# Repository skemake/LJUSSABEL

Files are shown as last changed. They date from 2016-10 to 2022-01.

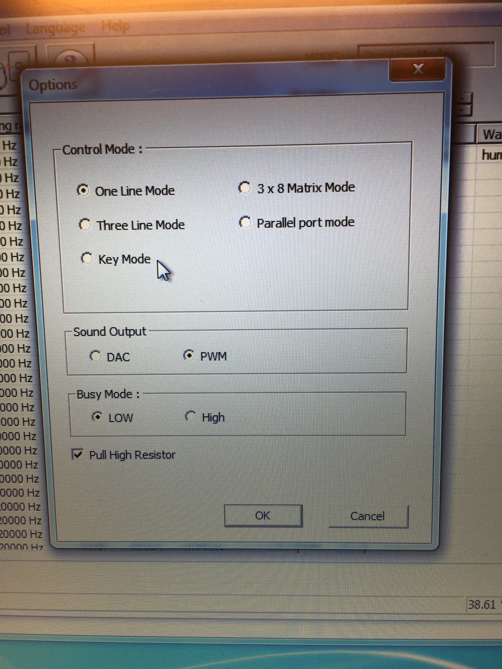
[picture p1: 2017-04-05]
Hardware/flags_wt588d_programmer.jpg

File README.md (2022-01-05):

#LJUSSABEL

##Introduction
LJUSSABEL is a low-cost, make-it-yourself lightsaber. Made with an aluminium shaft, tough polycarbonate blade and runs on an Arduino Pro Mini.

##Background
LJUSSABEL is the result of a question posed to one of SkeMakes founding members. A local martial arts club was invited to arrange a Star-Wars themed live roleplay event for kids at the annual game/movie/comic convention Nordsken. They had sourced some clear polycarbonate tubes from a company making snow season road markers and wanted to know if it was possible to find a cheap way to light them up to emulate lightsabers. After some intensive googling, our reply was: "Yes, and we can add sound to them too!". 

##What
The sabers feature light, sound and motion/clash sensitivity. They are tough enough to fight with (tested by the local Kendoka) and suitable for both kids and adults.

##Who
LJUSSABEL is developed by community and in collaboration with other non-profit organisations. The circuitry and design is made by one of our members and the soldering, programming and general problem solving has been done by the members on a volunteer basis.

It's a co-creative, open source, collaborative project made by creative makers and devoted people working together.

##Assembly instructions
Instructions (so far only in Swedish) for assembling a lightsaber are available in this document: https://docs.google.com/document/d/1xrwHwMRmk5lazxgZUJuRNKeTjP84kaqsUcIwcMbUZiY.

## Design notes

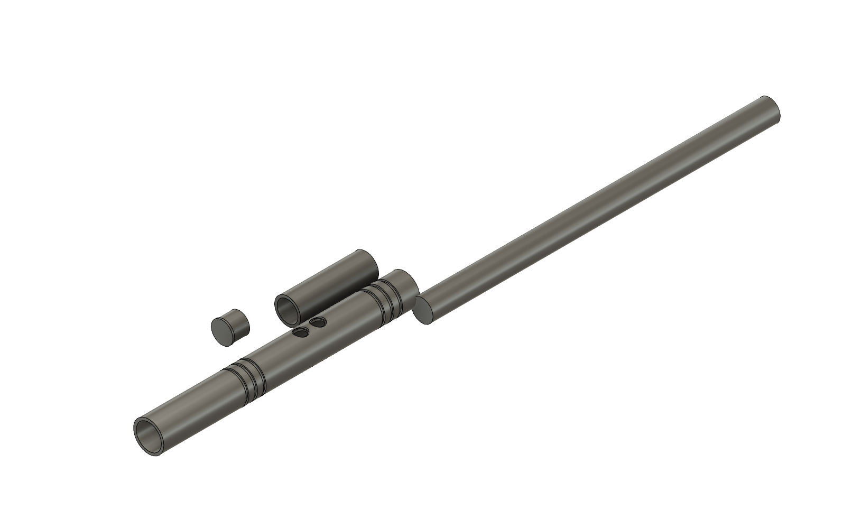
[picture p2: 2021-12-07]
Hardware/Drawings/LJUSSABEL.png

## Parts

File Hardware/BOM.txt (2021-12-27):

Bill of Materials

- Circuit board: After brd file in this repository

On top of this moderboard the following components are mounted:
- Moderboard: Arduino Pro Mini 328 - 5V/16MHz
- DC-DC converter: 5V to 3.3V
- Sound chip: WT588D
- Accelerometer: GY-61
- Power MOSFET: 3 pcs 14n05
- Diode: 2 pcs 1n4148
- Resistor: 1pcs 568ohm
- Vibration sensor: SW18010P

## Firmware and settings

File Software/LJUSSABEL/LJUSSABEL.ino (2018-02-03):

#include "OneButton.h"
#include "RGBLED.h"
#include "OneLineWT588D.h"
#include "Motion.h"
#include "SoundFont.h"
#include "SM.h"
#include "ColorGem.h"

// Uncomment next line to enable debug traces
//#define DEBUG
#include "Debug.h"

// Button
#define SW_ACT_PIN 8

// LED PWM pins
#define LED_RED_PIN 9
#define LED_GREEN_PIN 6
#define LED_BLUE_PIN 5

// Unused PWM pins for extra LED
//#define LED_ACCENT_RED_PIN 10
//#define LED_ACCENT_GREEN_PIN 3
//#define LED_ACCENT_BLUE_PIN 12

// Sound chip
#define WT588D_DATA_PIN 4
#define WT588D_BUSY_PIN 7
#define WT588D_RESET_PIN 11

// Accelerometer
#define GY_61_GND_PIN 13
#define GY_61_VCC_PIN A4
#define GY_61_X_PIN A2
#define GY_61_Y_PIN A1
#define GY_61_Z_PIN A0

// Clash switch
#define CLASH_PIN 2

// Crystal pins (voltage divider circuit)
#define COLOR_GEM_ANALOG_PIN A3
#define COLOR_GEM_DIGITAL_PIN 12

// Used to get random seed for sound selection
#define RANDOMSEED_PIN A5

// Global for clash sensor debounce
uint32_t clash_interrupt_time;
// Clash interrupt flag
bool clashInterruptTriggered=false;
// Do not trigger swings directly after clash
#define CLASH_SWING_OVERRIDE_DURATION 1000


// Minimum swing sound time
#define SWING_SOUND_DURATION 1000
uint32_t swing_interrupt_time;

// Init
OneButton ButtonAct(SW_ACT_PIN, true);
RGBLED Led(LED_RED_PIN,LED_GREEN_PIN,LED_BLUE_PIN);
OneLineWT588D Soundchip(WT588D_DATA_PIN,WT588D_BUSY_PIN,WT588D_RESET_PIN);
Motion Accelerometer(GY_61_X_PIN, GY_61_Y_PIN, GY_61_Z_PIN, 3.3, GY_61_VCC_PIN, GY_61_GND_PIN);
ColorGem BladeGem(COLOR_GEM_ANALOG_PIN, COLOR_GEM_DIGITAL_PIN);

//Set state machine to initial state.
State waitStateRunOnce(); // preallocate
State waitState(); // preallocate
SM Machine(waitStateRunOnce, waitState); // create state machine
void enterWaitState(){ Machine.Set(waitStateRunOnce, waitState); }
void enterLitState(){ Machine.Set(litStateRunOnce, litState); }
void enterLockupState(){ Machine.Set(lockupStateRunOnce, lockupState); }

void setup()
{
  trace_begin(115200);
  trace("Blade initializing...");

  Soundchip.warmUp();

  ButtonAct.setClickTicks(150); //600 default (debounce 60)
  ButtonAct.setPressTicks(500); // 1000 default

  // clash sensor
  digitalWrite (CLASH_PIN, HIGH);
  attachInterrupt(digitalPinToInterrupt(CLASH_PIN), clashInterrupt, FALLING);
  clash_interrupt_time = millis();

  swing_interrupt_time = millis();

  delay(200);

  // Init blade color
  trace(BladeGem.getValue());
  BladeGem.readGem();
  Led.setValue(BladeGem.getRed(),BladeGem.getGreen(),BladeGem.getBlue());

  //set seed for the random() in SoundFont.h
  randomSeed(analogRead(RANDOMSEED_PIN));
  enterWaitState();
}

void loop()
{
  // Update everything
  Accelerometer.update();
  ButtonAct.tick();
  Led.poke();
  EXEC(Machine);
}

State waitStateRunOnce()
{
  trace("Enter wait state.");
  // set button function pointers
  ButtonAct.attachClick(enterLitState);
  ButtonAct.attachLongPressStart(enterLitState);

  // disable other functions
  ButtonAct.attachDoubleClick(buttonDisabled);
  ButtonAct.attachDuringLongPress(buttonDisabled);
  ButtonAct.attachLongPressStop(buttonDisabled);

  // led off
  if(Led.fadeOut(500)) // returns true if led was on
  {
    Soundchip.play(getRandom(fx_poweroff));
  }
  else
  {
    Soundchip.play(getRandom(fx_boot));
    Led.turnOff();
  }
}

State waitState()
{
}

State litStateRunOnce()
{
  trace("Enter lit state.");

  // set button function pointers
  ButtonAct.attachClick(enterWaitState); // turn led off
  ButtonAct.attachLongPressStart(enterLockupState);

  // disable all else
  ButtonAct.attachDoubleClick(buttonDisabled);
  ButtonAct.attachDuringLongPress(buttonDisabled);
  ButtonAct.attachLongPressStop(buttonDisabled);

  // Clear any clash interrupts that happened in lockup state
  clashInterruptTriggered = false;

  Led.setFlicker(0);

  if(Led.fadeIn(500)) // returns true if led was off
  {
    Soundchip.play(getRandom(fx_poweron));
  }
  else
  { // led is on, so we should be humming already (e.g. returning from lockup)
    Soundchip.play(getRandom(fx_hum));
    Soundchip.repeat();
  }
}

State litState()
{
  if(Accelerometer.isSwinging())
  {
    swing();
  }

  if(clashInterruptTriggered)
  {
    clash();
  }

  // Restart humming if we have silence
  if(Soundchip.isBusy() == false)
  {
    trace("Restart humming");
    Soundchip.play(getRandom(fx_hum));
    Soundchip.repeat();
  }
}

State lockupStateRunOnce()
{
  trace("Enter lockup state.");

  // set button function pointers
  ButtonAct.attachClick(enterWaitState); // turn led off
  ButtonAct.attachLongPressStop(enterLitState);

  // disable all else
  ButtonAct.attachDoubleClick(buttonDisabled);
  ButtonAct.attachLongPressStart(buttonDisabled);
  ButtonAct.attachDuringLongPress(buttonDisabled);

  Soundchip.play(getRandom(fx_lockup));
  Soundchip.repeat();
}

State lockupState()
{
  Led.setFlicker(5);
}

/*
void deflect(){
  Led.flash(255,255,255);
  Soundchip.play(getRandom(fx_blaster));
}*/

void swing()
{
  if ((millis() - clash_interrupt_time) < CLASH_SWING_OVERRIDE_DURATION)
  {
    // Do not allow swings directly after clash, since the blade bounce oftern trigger flase swings
    trace("swing clash override");
  }
  else
  {
    if (millis() - swing_interrupt_time > SWING_SOUND_DURATION)
    {
      trace("Swing.");
      Accelerometer.swingTrace();
      Soundchip.play(getRandom(fx_swing));
      swing_interrupt_time = millis();
    }
  }
}

void clash()
{
  trace("Clash.");
  Led.flash(255,255,255);
  Soundchip.play(getRandom(fx_clash));
  clashInterruptTriggered = false;
}

void clashInterrupt()
{
  if(Led.getState()==on)
  {
    if (millis() - clash_interrupt_time > 200)
    {
      clashInterruptTriggered = true;
      trace("interrupt");
      clash_interrupt_time = millis();
    }
  }
}

void buttonDisabled()
{
  // do nothing
}

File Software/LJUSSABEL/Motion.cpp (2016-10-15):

#include "Motion.h"

//#define DEBUG
#include "Debug.h"


Motion::Motion(uint8_t pin_x, uint8_t pin_y, uint8_t pin_z, float aref, uint8_t pin_vcc, uint8_t pin_gnd){
	pinMode(pin_gnd, OUTPUT);
	digitalWrite(pin_gnd, LOW);
	pinMode(pin_vcc, OUTPUT);
	digitalWrite(pin_vcc, HIGH);
	
	_aref = aref;
	_pin_x = pin_x;
	_pin_y = pin_y;
	_pin_z = pin_z;
	_mvG = aref / 10.0;
	_bias = aref / 2.0;
	_rad2deg = 180.0 / M_PI;
  _swing_start_time = millis();
  _deltaX=0;
  _deltaY=0;
  _deltaZ=0;
}
void Motion::update(){
	_xg = getGravity(analogRead(_pin_x));
	_yg = getGravity(analogRead(_pin_y));
	_zg = getGravity(analogRead(_pin_z));

  if (millis() - _swing_start_time > SWING_SAMPLE_TIME)
  {
    _deltaX = _maxX - _minX;
    _deltaY = _maxY - _minY;
    _deltaZ = _maxZ - _minZ;
    
    _minX=_xg;
    _maxX=_xg;
    _minY=_yg;
    _maxY=_yg;
    _minZ=_zg;
    _maxZ=_zg;
    
    _swing_start_time = millis();
  }
  if(_xg < _minX) _minX = _xg;
  if(_xg > _maxX) _maxX = _xg;
  if(_yg < _minY) _minY = _yg;
  if(_yg > _maxY) _maxY = _yg;
  if(_zg < _minZ) _minZ = _zg;
  if(_zg > _maxZ) _maxZ = _zg;

}

float Motion::getDeltaSum()
{
  return (_deltaX + _deltaY + _deltaZ);
}

float Motion::getGravity(uint16_t reading)
{
  float voltage = reading * _aref;
  voltage /= 1024.0;

  //minus the zero g bias
  //then divide by mv/g
  //which when Vs = 3.3V, V/g = 0.330
  float gv = (voltage - _bias) / _mvG;

  return gv;
}

void Motion::swingTrace()
{
  trace(_deltaX);
  trace(_deltaY);
  trace(_deltaZ);
}

bool Motion::isSwinging()
{
  return ((getDeltaSum() >= 1) && (getDeltaSum() < 3));
		//return (getSquared() >= _swingThreshold);
}

bool Motion::increaseSwingThreshold(){
	if(_swingThreshold==SWING_THRESHOLD_MAX){
		return false;
	}else{
		_swingThreshold++;
		return true;
	}
}
bool Motion::decreaseSwingThreshold(){
	if(_swingThreshold==SWING_THRESHOLD_MIN){
		return false;
	}else{
		_swingThreshold--;
		return true;
	}
}
uint8_t Motion::getSquared(){
	return ((_xg*_xg)+(_yg*_yg)+(_zg*_zg));
}

float Motion::getX()
{
  return _xg;
}

float Motion::getY()
{
  return _yg;
}

float Motion::getZ()
{
  return _zg;
}

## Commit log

2016-10-18 BRD-file of PCB
    Inital release - sch file will come soon.
    [2016-09-29.brd]
2016-11-25 Increase drillsize for MOSFETS
    Due to error in eagle the drillsize was 0.08mm to small for the
    standard TO-251 IPAK package. Fixed now.
    [2016-09-29.brd]
2017-04-06 Added check of busy pin
    First sample played will be the "lockup" sound
    If the busy pin is working this sound will play for a couple of seconds
    If busy pin is faulty the lockup sound will only play for 500ms
2018-01-02 gerber for orders
2018-02-03 start with long press and short press (fix by Anders)
    [LJUSSABEL.ino]
